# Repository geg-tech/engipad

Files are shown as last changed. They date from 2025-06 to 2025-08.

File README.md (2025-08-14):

# EngiPad - The Construction PDA Macropad
> update! i remade the PCB for this macropad in the brand spankin new folder named **ENGIPAD \\\ V2**! this readme and repo currently covers version 1 of the build (which is now finished)

This is a 8-key Hackpad with RGB lighting and an integrated OLED display in the case, modeled after the Engineer's PDA from *Team Fortress 2*. <br/>
[*see it in action in this handy dandy youtube video!*](https://youtu.be/H9Vl-Haxy5c)

screenie
IMG_7791 Large

The idea came a couple days ago, when I was scrolling through the TF2 wiki and noticed that the PDA would make for a *fire* macropad. I had extra time on hand and was waiting for the parts to come in for my main project, [The Biblically Accurate Keyboard](https://github.com/hunkegg/biblicallyaccuratekeyboard), so I decided to go ahead and try to speedrun designing an actual macropad this time. <br/>
I aimed to be as game accurate as possible, using pictures and screenshots from the game to model and render my case. <br/>

Speaking of the Engineer, I made my macropad work with my custom keybinds for Fusion 360, making tools that I often use like Project and Move more accessible to me while I work on engineering and CAD projects.

Made as part of Hackpad! (and the design competition due in like 4 days lmfao)

### Features!
* 8 keys
* OLED display and RGB
* Custom case and keycaps modeled after the Engineer's Construction PDA
* An alternate CAD file to fit a metal toggle switch I have on hand
* QMK firmware
* TF2 inspired silkscreen on the front and Highway silkscreen on the back
* 5 different key layers, set to keybinds for general use, Discord, Youtube, Minecraft, and Fusion 360

## CAD
render
assembled
exploded
exploded but rendered <br/>

> (The CAD for this case is made from scratch for anyone thinking that I just used the TF2 game files; refer to the mile long Fusion timeline and scroll bar below)


## PCB + Schematic
schematic
PCB
front side

> (note: the back silkscreen in the first PCB view is hidden since it looks very cluttered with it visible)

## BOM

| part | quantity |
|---|---|
| Cherry MX Switches | 8 |
| SK6812 MINI-E LEDs | 8 |
| 0.91 inch OLED display | 1 |
| M3 16mm Screws | 4 |
| Seeed Studio XIAO RP2040 | 1 |
| Wires (to connect OLED) | 1 |
| 3D Printed Case (all parts) | 1 |
| 3D Printed Keycaps | 8 |
| PCB | 1 |
| Super Glue | 1 | <br/>

note: wires, super glue, and a 3D printer to make the case/keycaps are already owned! <br/>

## extras

### Credit and Thanks
* Huge credit to [@samliu's Squarepad](https://github.com/samdev-7/squarepad/tree/main)! Their slot design for the OLED inspired a good chunk of the CAD for this macropad, which is seen in the split apart screen with the OLED sandwiched in between
* A random website online that hosted the model files for the Engineer's PDA models, which allowed me to get accurate reference photos via Blender
* The people behind Highway and Hackpad as always :3

also i couldn't find anywhere to fit a picture of the actual PDA from the game so it goes here


engi

A badge of a Cerberus and a raccoon laughing together, with the text "HIGHWAY" and "HACK CLUB" beside them.

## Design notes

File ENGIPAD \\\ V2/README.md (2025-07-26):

# The EngiPad REMASTERED
the old pcb was honestly kinda ass so i remade it <br/>

V2 is currently a WIP! refer to the list below for development <br/>
* ✅ - PCB revamp
* ✅ - new art
* ❌ - case/CAD remodel
* ❌ - rewriting firmware

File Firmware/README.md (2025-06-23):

# hello welcome to da firmware store
FYI, This firmware is using QMK! <br/>
Right now, the keymap is fully set up, with the OLED displaying "engineer gamin" and the RGB set to a pre-made RGB pattern. I plan to remake and fine tune the OLED and RGB once the parts come in, but this will do for now :3 <br/> 



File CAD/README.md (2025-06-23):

# HELP!!! WHICH PARTS ARE WHICH!!!!!
boo

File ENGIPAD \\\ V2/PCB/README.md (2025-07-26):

# the old pcb sucked so i remade it
CHANGES!!!!!!!
* revamped RGB, now with more flashy lights and actually fixed footprints/wiring
* optional encoder, for if you want to replace the decorational rocker switch with something more functional or if you wanna ditch the case entirely
* fixed OLED footprint, now supports direct soldering to the board (idk how i messed this up the first time lmfao)

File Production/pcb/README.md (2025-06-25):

# welcome to the gerber part of production
made for your convenience! (and to not lose everything in a pile of 30000 github files)

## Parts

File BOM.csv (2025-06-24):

Part Name | Quantity | Notes
Cherry MX Switches | 8
SK6812 MINI-E LEDs | 8
0.91 inch OLED display | 1
M3 16mm Screws | 4
Seeed Studio XIAO RP2040 | 1
Wires (to connect OLED) | 1 | Already Owned
3D Printed Case (all parts) | 1 | Can 3D print
3D Printed Keycaps | 8 | Can 3D print
PCB | 1
Super Glue | 1 | Already Owned

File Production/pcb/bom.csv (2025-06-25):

Designator | Footprint | Quantity | Value | LCSC Part #
D1, D12, D13, D14, D15, D16, D2, D3 | LED_SK6812MINI_PLCC4_3.5x3.5mm_P1.75mm | 8 | SK6812MINI
OLED1 | PinHeader_1x04_P2.54mm_Vertical | 1 | ~
SW1, SW2, SW3, SW4, SW5, SW6, SW7, SW8 | SW_Cherry_MX_1.00u_PCB | 8 | SW_Push
U1 | XIAO-RP2040-DIP | 1 | XIAO-RP2040-DIP

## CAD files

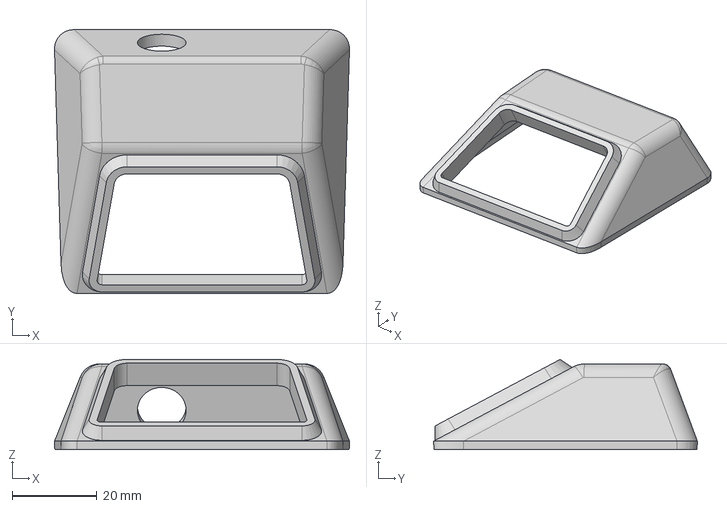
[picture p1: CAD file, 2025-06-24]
CAD/engipad (toggle switch variant).step
69.6 x 62.2 x 21.3 mm

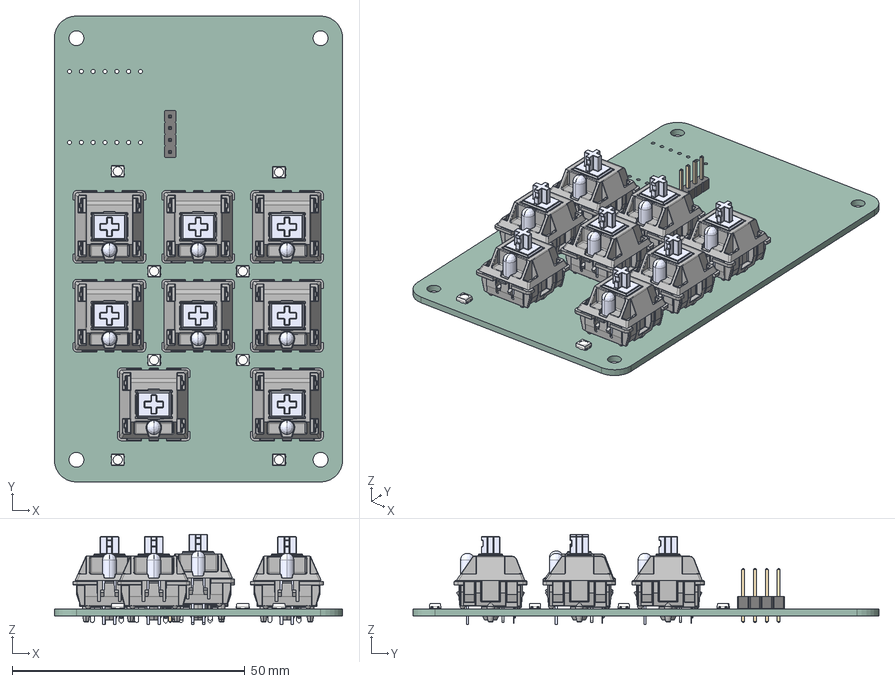
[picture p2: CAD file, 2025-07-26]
ENGIPAD \\\ V2/PCB/engiboard.step
61.9 x 100.0 x 19.4 mm
DOUT x 8
DIN x 8
VSS x 8
VDD x 8
MX Öá °´¼ü¡ä_¨¹___¡§1 x 8
MX ס סͥ¨¢¨¬_¡§¡顧__ x 8
MXס ϞñLEDLEDLED x 8
MXÖá ÖáÌå µ×²¿ ¦Ì¡Á2__Ä¬ÈÏ_¨¢2____¨¨_ x 8
֫½ğ__Ĭɏ__¨¨_ x 8
PinHeader_1x04_P2.54mm_Vertical
engiboard_PCB

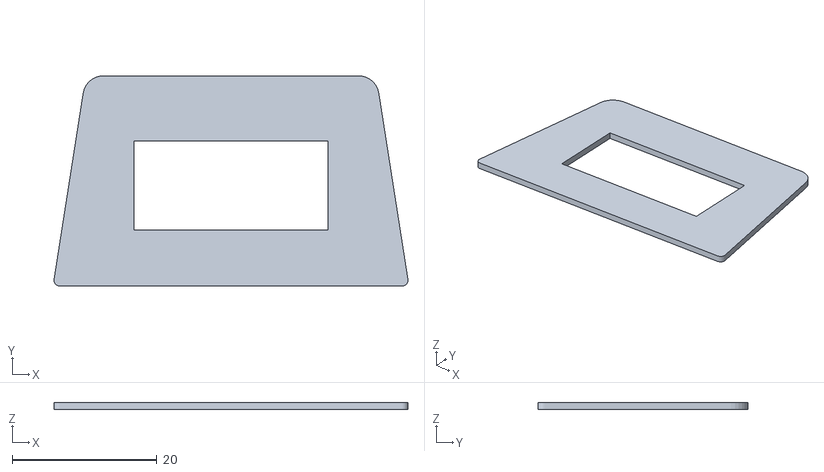
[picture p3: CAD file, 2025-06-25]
Production/cad/screen plate.stl
48.9 x 29.0 x 1.00

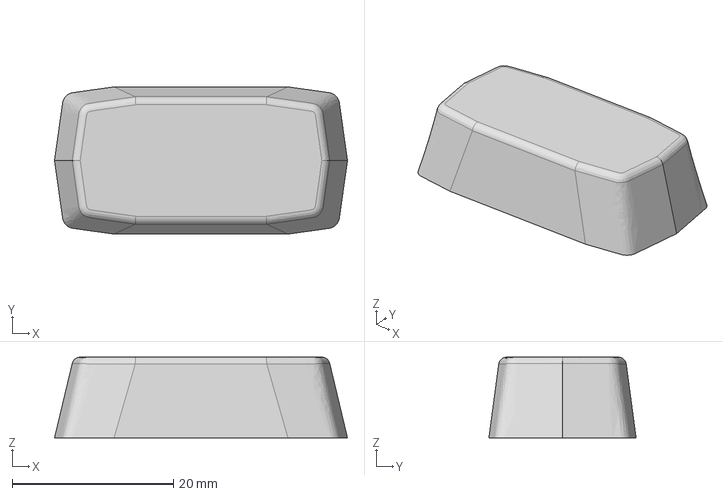
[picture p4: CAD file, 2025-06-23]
CAD/long engicap.step
36.3 x 18.2 x 10.0 mm

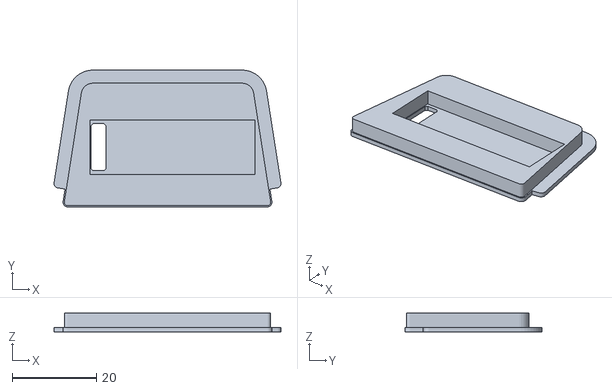
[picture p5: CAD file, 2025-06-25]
Production/cad/screen holder.stl
53.8 x 32.4 x 4.40

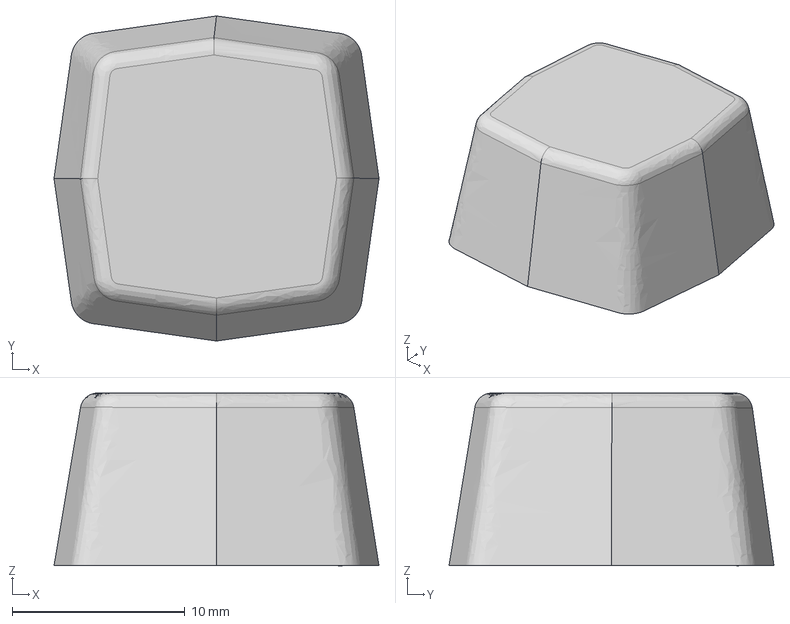
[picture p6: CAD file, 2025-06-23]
CAD/engicap.step
18.8 x 18.8 x 10.0 mm

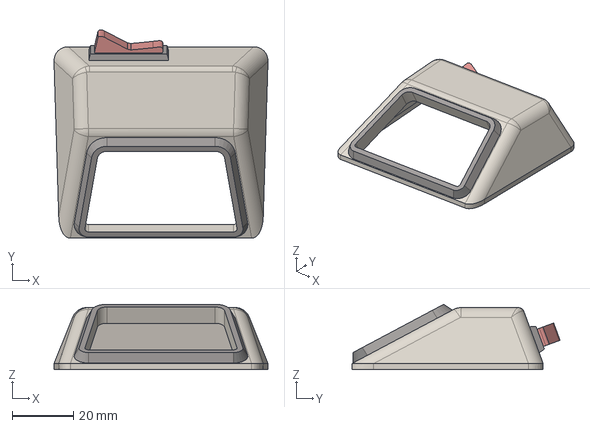
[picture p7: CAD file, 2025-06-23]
CAD/screen shell.step
69.6 x 67.7 x 21.3 mm

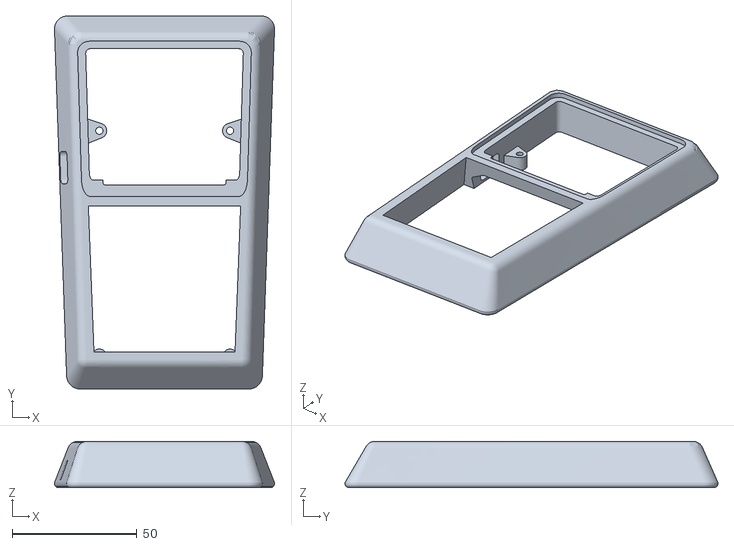
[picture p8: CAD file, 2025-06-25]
Production/cad/top shell.stl
88.2 x 149.5 x 18.5

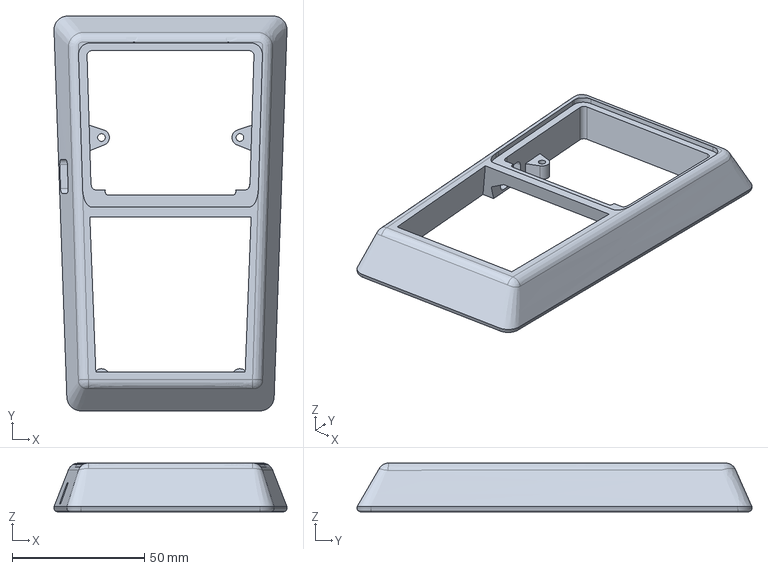
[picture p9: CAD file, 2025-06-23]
CAD/top shell.step
88.2 x 149.5 x 18.5 mm

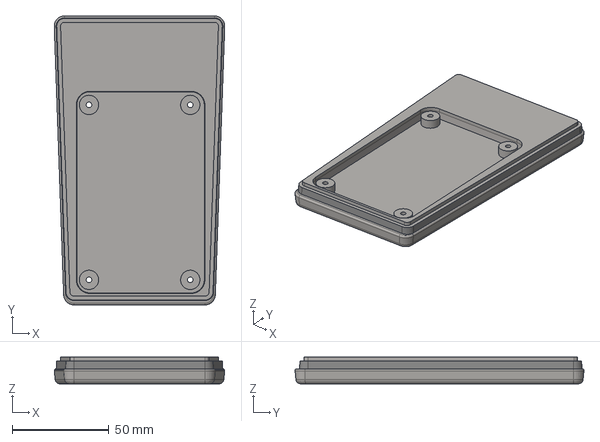
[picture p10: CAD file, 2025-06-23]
CAD/bottom shell.step
88.2 x 149.5 x 13.8 mm

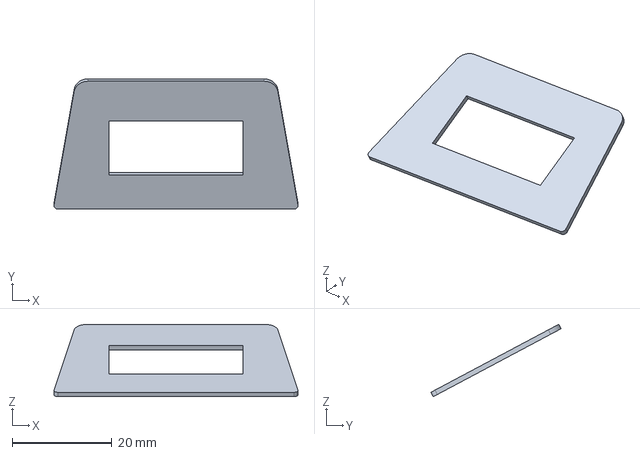
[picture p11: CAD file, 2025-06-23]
CAD/screen plate.step
48.9 x 26.1 x 14.5 mm

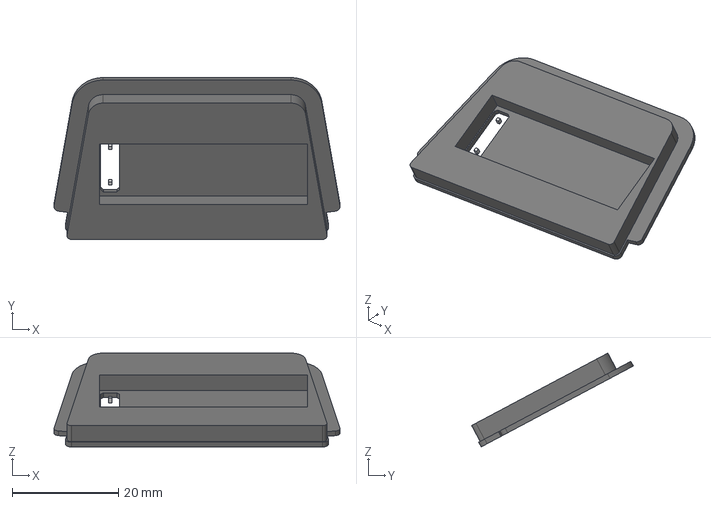
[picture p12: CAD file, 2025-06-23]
CAD/screen holder.step
53.8 x 30.4 x 17.7 mm

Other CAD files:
Production/cad/long engicap.stl
Production/cad/screen shell.stl
Production/cad/bottom shell.stl
Production/cad/engicap.stl

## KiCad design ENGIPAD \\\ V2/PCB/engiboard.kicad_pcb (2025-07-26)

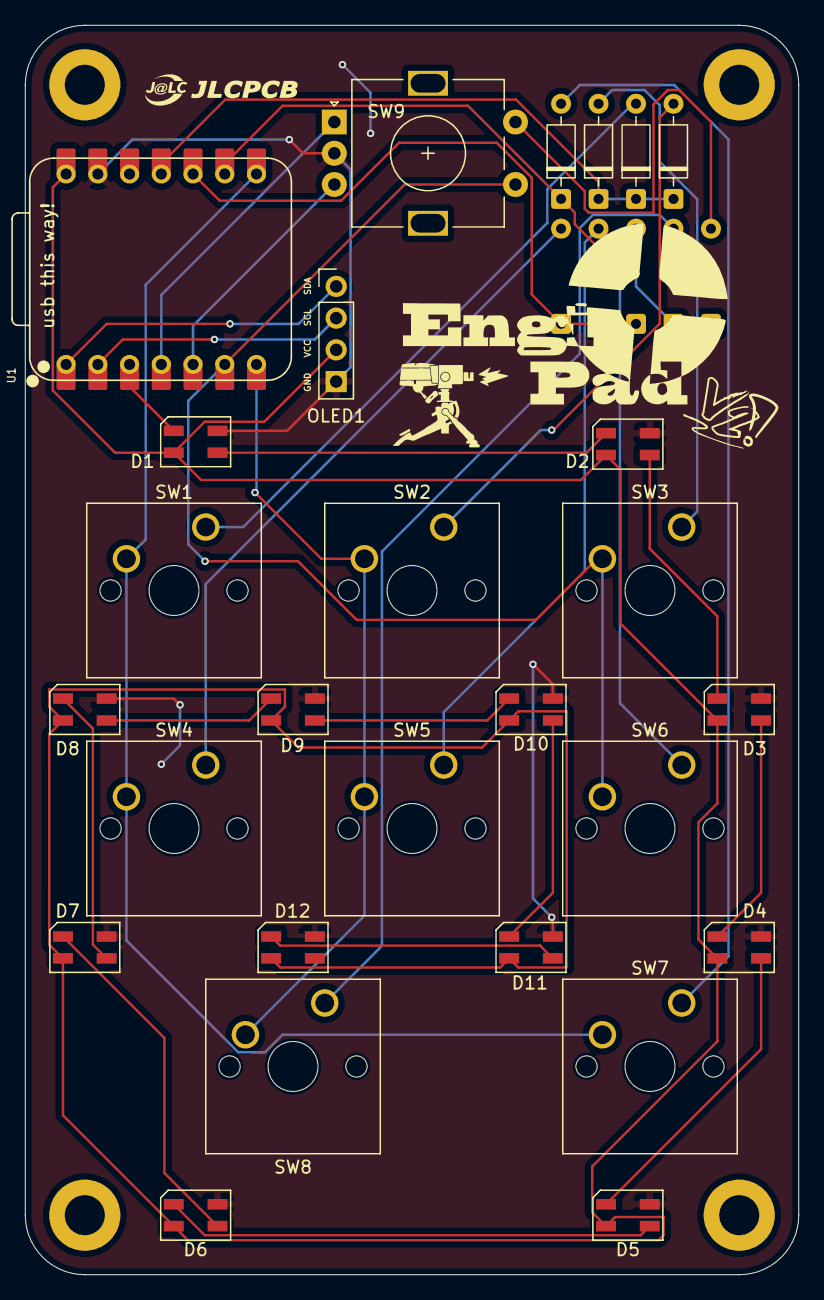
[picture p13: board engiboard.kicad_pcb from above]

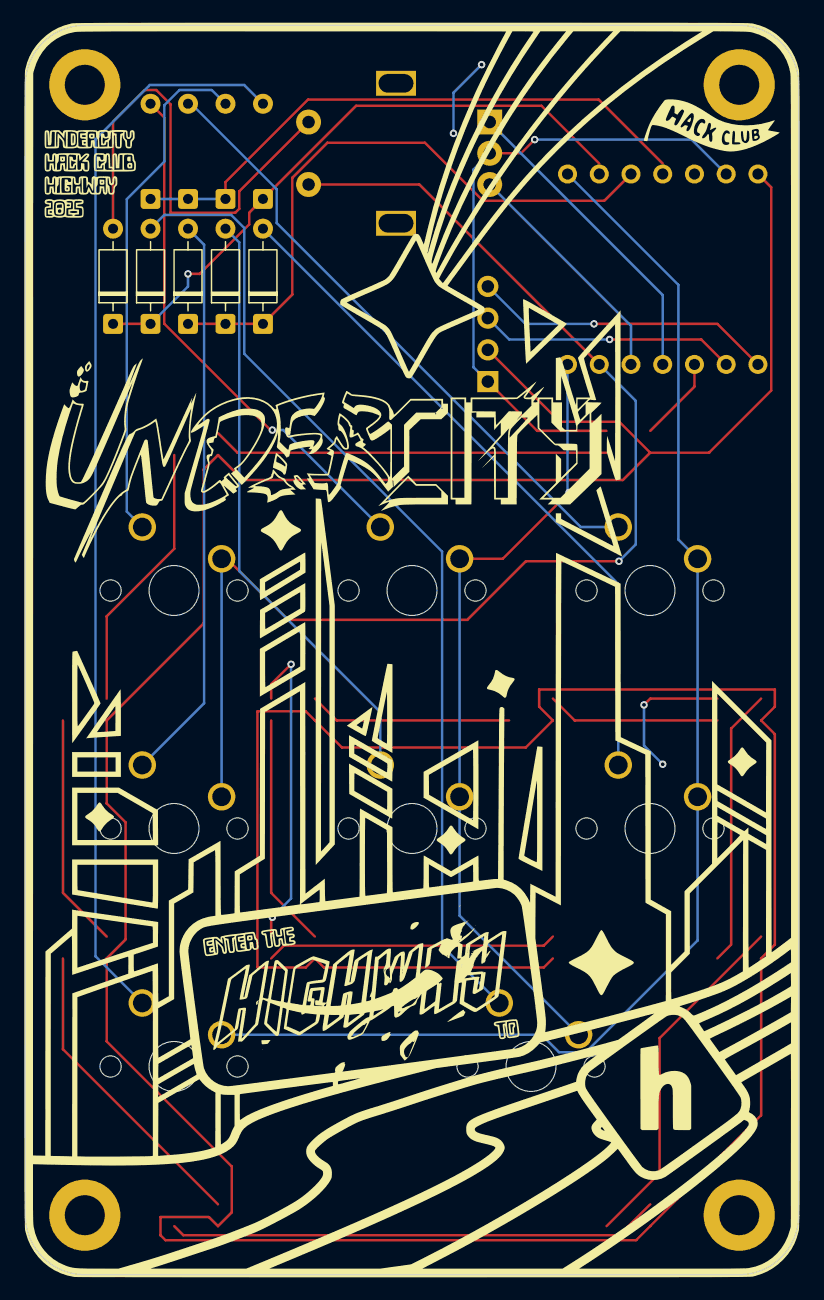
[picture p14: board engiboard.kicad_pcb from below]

Board: 2 copper layers, 61.9 x 100.0 mm, 32 parts (5 on the bottom side), 33 nets.

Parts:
D1, D2, D3, D4, D5, D6, D7, D8, D9, D10, D11, D12: SK6812MINI; LED_SK6812MINI_PLCC4_3.5x3.5mm_P1.75mm
D13, D14, D15, D16, D17, D18, D19, D20, D21: 1N4148; D_DO-35_SOD27_P7.62mm_Horizontal
OLED1: PinHeader_1x04_P2.54mm_Vertical
SW1, SW2, SW3, SW4, SW5, SW6, SW7, SW8: SW_Push; SW_Cherry_MX_1.00u_PCB
SW9: RotaryEncoder_Switch; RotaryEncoder_Alps_EC11E-Switch_Vertical_H20mm
U1: XIAO-RP2040-DIP

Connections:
+5V: D1.4 (VDD), D2.4 (VDD), D3.4 (VDD), D4.4 (VDD), D5.4 (VDD), D6.4 (VDD), D7.4 (VDD), D8.4 (VDD), D9.4 (VDD), D10.4 (VDD), D11.4 (VDD), D12.4 (VDD), OLED1.3 (SCL), U1.14 (VBUS)
COL1: SW1.2, SW4.2, SW7.2, U1.8 (GPIO1/RX)
COL2: SW2.2, SW5.2, SW8.2, U1.7 (GPIO0/TX)
COL-KNB: SW3.2, SW6.2, SW9.S1, U1.6 (GPIO7/SCL)
GND: D1.2 (VSS), D2.2 (VSS), D3.2 (VSS), D4.2 (VSS), D5.2 (VSS), D6.2 (VSS), D7.2 (VSS), D8.2 (VSS), D9.2 (VSS), D10.2 (VSS), D11.2 (VSS), D12.2 (VSS), OLED1.4 (SDA), SW9.C, U1.13 (GND)
KNB-A: SW9.A, U1.4 (GPIO29/ADC3/A3)
KNB-B: SW9.B, U1.5 (GPIO6/SDA)
LED: D1.3 (DIN), U1.3 (GPIO28/ADC2/A2)
unnamed: D1.1 (DOUT), D2.3 (DIN)
unnamed: D2.1 (DOUT), D3.3 (DIN)
unnamed: D3.1 (DOUT), D4.3 (DIN)
unnamed: D4.1 (DOUT), D5.3 (DIN)
unnamed: D5.1 (DOUT), D6.3 (DIN)
unnamed: D6.1 (DOUT), D7.3 (DIN)
unnamed: D7.1 (DOUT), D8.3 (DIN)
unnamed: D8.1 (DOUT), D9.3 (DIN)
unnamed: D9.1 (DOUT), D10.3 (DIN)
unnamed: D10.1 (DOUT), D11.3 (DIN)
unnamed: D11.1 (DOUT), D12.3 (DIN)
unnamed: D13.2 (A), SW1.1
unnamed: D14.2 (A), SW2.1
unnamed: D15.2 (A), SW3.1
unnamed: D16.2 (A), SW4.1
unnamed: D17.2 (A), SW5.1
unnamed: D18.2 (A), SW6.1
unnamed: D19.2 (A), SW7.1
unnamed: D20.2 (A), SW8.1
ROW1: D13.1 (K), D14.1 (K), D15.1 (K), U1.11 (GPIO3/MOSI)
ROW2: D16.1 (K), D17.1 (K), D18.1 (K), U1.10 (GPIO4/MISO)
ROW3: D19.1 (K), D20.1 (K), D21.1 (K), U1.9 (GPIO2/SCK)
ROW-KNB: D21.2 (A), SW9.S2
SCL: OLED1.2 (VCC), U1.2 (GPIO27/ADC1/A1)
SDA: OLED1.1 (GND), U1.1 (GPIO26/ADC0/A0)

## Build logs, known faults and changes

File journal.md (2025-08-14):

---
title: "EngiPad"
author: "egg splats"
description: "The Engineer's Construction PDA from Team Fortress 2, now as a macropad!"
created_at: "2025-06-20"
---

# Hours at time of submission): 16 hours
# Total Hours: 29 Hours

back at it with another project :3 <br/>
this time a quick one! <br/>
(dates are again in mm/dd/yy cuz 🦅) <br/>

## 6/21/25 - started planning and designing in KiCad
we locking in for this one 🗣️🗣️🔥 <br/> 

For this Hackpad, I plan to base it off of the [TF2 Engineer's Construction PDA](https://wiki.teamfortress.com/wiki/PDA), which has 8 switches and a rocker switch. <br/>

 <br/>
 
Looking at the model, the macropad can be split into two halves with the split going down the dark grey, with the PCB and electronics on the bottom half and the rest of the case going on top.

 <br/>

After I got the general plan down, I started to design the PCB in KiCad, starting with the schematic. I first considered doing a matrix-style wiring for the switches, but then settled on doing direct wiring since the Hackpad microcontroller has enough GPIO to support 8 switches and LEDs and the fact that matrix wiring requires diodes which take up space on the PCB. <br/>
I also decided to add on an OLED screen to the macropad, putting the OLED in a slot inside the PDA's screen. I originally planned not to do this idea since the OLED didn't have any screw holes, but then I was inspired by **samliu's** solution by having a slot in their macropad case, as seen in their [Squarepad's](https://github.com/samdev-7/squarepad) CAD.<br/>

schematic <br/>
 <br/>

After I got the schematic, I started to work on the PCB design, mirroring the 3x3 grid of the Engineer's PDA with the 8th key taking up twice the space and adding RGB lights between the switches. I considered having the PCB extend throughout the macropad, but found it easier to place the RP2040 going to the side to compact the PCB below 100mm x 100mm in order to save money. <br/>
I also threw in some silkscreen art, making a TF2 inspired graphic for the front and a Highway backside, as well as a lanyard hole for extra PCBs! <br/>
pcb
front
back<br/>
> note: i disabled the silkscreen in the PCB view since it made the board look very cluttered lol <br/>

I made the backside with Figma, using the frame technique I learned from the Highway Figma magazine to place and design my back silkscreen (and is by far my favorite pcb made yet :3) <br/>

 <br/>
> I used an orthographic screenshot of the PCB's backside and used Figma to draw out shapes to put on the silkscreen! The graphic was made in black and white since it's the easiest format for KiCad's image converter to work with

time spent: 6 hours planning, designing PCB, and making art

## 6/22/25 - cadding the case
After finishing my PCB, I started working on the case. While I *could* lazily take the game files for the PDA and port them into a model, I figured that ripping and using the *exact* models from the game would definitely NOT be allowed in Highway (plus the fact that it's lame and boring). <br/>
This left me with recreating the model in Fusion. I found a source online that had the original model for the PDA, and managed to import them into Blender to take pictures to aid in designing. <br/>



 <br/>
 <br/>

After a while, I finished most the CAD for the case. I split the case apart into the two shells, as detailed above, as well as splitting the trapezoidal screen part thingy into it's own section. <br/>

 <br/>

To mount the OLED in the screen section, I made two halves of the PDA's screen and "sandwiched" the OLED in between those two halves, with the headers poking out to connect to the PCB. The two halves are then slotted into the main shell for the screen, with the back side of one of the halves having a ledge for easy gluing. <br/>
I initially thought of using some tiny screws to mount the two halves, but was soon shut down due to the screws being too big for this scale and my printer not having *that* level of precision, especially at an angle. <br/>

 
<br/>

The two case halves are mounted with the PCB in a sandwich style mounting, with the PCB in between of the screw holes in the case shells. The case halves also have a small lip where they can interlock to improve alignment and ease of building, which is used between the top shell and the screen section. <br/>


 <br/>

For the rocker switch, I used a 11.5mm wide hole to put my own toggle switch in (the metal lever one). I *did* find an actual rocker switch like the one in-game, but it was too large for my scale. I aimed to be as game-accurate for this CAD as possible, but using an actual switch was honestly too cool to pass up in my opinion. <br/>

 <br/>

However, for people who don't have a cool metal switch, I also made an alternate version of the screen shell with a rocker switch. (unfunctional though, sorry) <br/>

 <br/>

Speaking of being game-accurate, I noticed that the keycaps on the actual PDA model weren't perfectly square, but more like octogons in a way. This led to me designing my own custom keycaps, modeling them after the buttons on the Engineer's PDA. <br/>

 <br/>

I didn't have time to color and render the model, but I will most likely finish modeling and the Hackpad tomorrow
time: 6 hours cadding

## 6/23/25 - Rendering and finishing up 
This morning I managed to color the Fusion model and render it. <br/>
I took a screenshot of the PDA from the TF2 Wiki and took apart the colors, applying it to the CAD model. <br/>

 <br/>

I also SEVERELY underestimated the Render tool in Fusion, because it made the colored CAD model look so much better like wtf :sob: <br/>

engipad
exploded
top

Once I had the CAD down, I started to work on the firmware. I picked QMK for the firmware, since I have experience using it from my other Highway project. I followed the guide found [here](https://docs.qmk.fm/porting_your_keyboard_to_qmk), and made a folder containing the keyboard and keymap .json files. <br/>



I edited the code to fit my Hackpad's direct, 8-key wiring, as well as setting the keybinds to correspond with shortcuts for Fusion commands, like Shift for selecting multiple elements or rotating the camera and E to extrude. I also added undo and redo macros, since I always forget what shortcut redo is lol <br/>

 <br/>

 <br/>

I also set up the code for the OLED and RGB, making the OLED print out "engineer gamin" for now and the RGB set to a default RGB pattern by QMK. I plan to fine tune and test out the firmware more accurately when the Hackpad parts come in, but this will do for now.

After I got the firmware setup, I began working on my README and preparing this repo for submission :D

current time: 4 hours rendering, programming QMK firmware, and setting up for submission

## 7/2/25 - parts came in
the parts actually came in two days ago but i was lazy so im putting this under today <br/>

Got my parts from hack club! <br/>
I 3D printed my custom keycaps using the last of my black filament and test fitted the keycaps on the switches. I was worried about my printer screwing up the stem geometry, but turned out the outer diameter of the stem was too big to fit in the switch (6mm wide to the switches' 5.4mm size limit). <br/>

Once I got the keycaps down, I turned to the hardware, soldering the headers onto the OLED and rp2040 and then flashing the firmware. The current firmware was preliminary, so only part of it worked with many of the features like the OLED and RGB not implemented, so I started work on that. <br/>

Once I made a proper keybaord setup with QMK, I started to work on the *keyboard.json* and *keymap.c* files. <br/>
I thought my current matrix setup would work, but QMK would refuse to compile it. I thought it was something to do with the microcontroller or me setting up QMK incorrectly, but ended up being an issue with the GPIO pin names. I initially put in the pin names found on the [Seeed Studio store page](https://www.seeedstudio.com/XIAO-RP2040-v1-0-p-5026.html) (D1, D2, D3, etc.), but QMK only recognizes the original GPIO names on the chip, meaning that I had to go into my schematic and adjust the GPIO names to the ones on the rp2040 chip. <br/>

 <br/>

The firmware managed to compile and work when I connected GND to the GPIO pins, which left me with coding the RGB and OLED. <br/>
There *really* wasn't any good sources online from my very short research into Google, since many of the wiki pages and videos referenced a rules.mk and config file that *should* have been made with the keybaord, so I went into [@alexren's Orpheuspad](https://github.com/hackclub/hackpad/tree/03a6a5542e0cffbb43e530b67994741fcccb205e/hackpads/orpheuspad/firmware/QMK) for reference on how to implement OLED and RGB. <br/>
Turns out, I was supposed to make my **own** rules.mk and config.h file inside the keyboard, so I proceeded to make those files and put in the settings for the additions. I'm not able to test out the rgb as of now since my PCB isn't here, but I managed to get the OLED screen working with QMK. <br/>

I used the QMK wiki page for [oled drivers](https://docs.qmk.fm/features/oled_driver) and tweaked around with the code for the logo, and managed to get the OLED to display my own custom image by making my own *glcdfont.c* file and pasting in code from this [logo editor](https://joric.github.io/qle/). <br/>
I made the custom image with photoshop, down sizing and adjusting the images used for my PCB's silkscreen art. <br/>



engipad-banner

time spent: 5 hours soldering, coding hardware, and redesigning keycaps

## 7/10/25 - Painting
Today I spent the entire morning painting wow <br/>
I got some cheap matte acrylic from Walmart on a grocery trip a while back, and used those and some old paints from my brother to make the colors on the PDA. This was also my first time actually *painting* a 3D print, as well as trying to match colors with mixing paints and such. <br/>



It was surprisingly hard to try to match the colors, since the black I used either overpowered everything and made it super dark or did nothing (tbh skill issue on my part) <br/>
After a while, I got the parts to a pretty good match, with the keys/case being dark grey, cream, or a maroon type color. <br/>

After letting them dry, I put together the case. The parts were a bit hard to fit now that they had a coat of paint messing up the tolerances, but they ended up friction fitting themselves pretty nicely.

yowza
yowza Small
IMG_7777 Small <br/>

time spent: 8 hours painting (holy :sob:)

## 7/25/25 - Finalizing Firmware
Today I started to finalize the firmware. <br/>
I initially planned to set the macropad to just Fusion keybinds, but out of sheer curiosity I decided to tinker around with key layers and macros. <br/>
I used the QMK wiki and the [OrpheusPad GitHub](https://github.com/hackclub/hackpad/blob/03a6a5542e0cffbb43e530b67994741fcccb205e/hackpads/orpheuspad/firmware/QMK/keymaps/default/keymap.c) to piece together how to use layers and ended up with the following code: <br/>

 <br/>

After I got the layers working, I started work on showing the layer setting on the OLED. The logo I made earlier only took up the bottom 3 rows out of 4 on the OLED, so I could use the first row to show the layer. <br/>

switcher-ezgif com-optimize

To actually switch the layers, I found a handy [Reddit comment](https://www.reddit.com/r/olkb/comments/1h5jja5/comment/m07eidj/) from a while back that makes layer switching pretty obvious. It's probably not efficient, but it's awfully simple and works for my scale. <br/>

After I fully fleshed out the layers, I got to configuring the macros and keybinds to each layer. I did a lil research on the keybinds found on each website/app I wanted to use the macropad on, such as discord and youtube, and filled out the keymap. <br/>

 <br/>

For certain shortcuts like muting or opening F3 keystrokes, I made macros for each of them. For some reason, the built in undo keycode for QMK doesn't work on my macbook, so I also had to make a custom macro for that too <br/>

 <br/>

I also made a custom macro as a reference to one of my friends, which literally replaces all typed text with yo <br/>



lowk i forgot how long i took on this part, but Hackatime says I took about 5 hours which is kinda wild imo <br/>

 <br/>

### time spent: 5 hours

## post build update
shipped this macropad :DDDD <br/>

i also made a post about it in my [personal slack channel](https://hackclub.slack.com/archives/C096FEXCM8T/p1753489905242969) with additional videos of it working in the README.md and on [reddit](https://www.reddit.com/r/tf2/comments/1m9iodj/recreated_the_engineers_construction_pda_as_a/) <br/>

Overall, I'm *really* proud of this project. I practically grew up on TF2, being shown youtube poops and shitposts by my older brothers about it and being a pretty active (and shitty) engi main, so having something I'm familiar with and fond of is really cool. <br/>
This was also my first time genuinely painting and post-processing a print/project before, since many of the smaller projects I've did before had minor sanding and pretty much zero to no painting, so having this experience was definitely a game changer for me.
> I'm in the process of painting the biblically accurate keyboard btw (it's a massive pain to handwire)

***While this is the final product***, I also made a V2 in my personal time! I redesigned the PCB to support an optional encoder, revamped some footprints, and added a matrix configuration to support the encoder as a switch. I also added and fixed some of the RGB lights, totaling to 12 lights. <br/>
I also revamped the backside art, which is possibly my *favorite* art so far along side the hacker card I made a while back. <br/>

 <br/>
 <br/>
 <br/>

I already returned the grant, so I'll most likely have to pay this out of pocket or use Grounded, but it was a nice challenge (and honestly really relaxing) to remake the PCB.

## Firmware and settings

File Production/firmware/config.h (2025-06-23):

#pragma once

#ifdef RGBLIGHT_ENABLE
    #define RGBLIGHT_LED_COUNT 8 

    #define RGBLIGHT_EFFECT_RGB_TEST

    #define RGBLIGHT_LIMIT_VAL 225
    #define RGBLIGHT_HUE_STEP 10
    #define RGBLIGHT_SAT_STEP 17
    #define RGBLIGHT_VAL_STEP 17
#endif
